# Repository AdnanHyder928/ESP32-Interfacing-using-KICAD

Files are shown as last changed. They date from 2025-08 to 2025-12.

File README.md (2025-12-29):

<h1>Schematic Section</h1>


<h1>PCB Section</h1>


<h1>3D Model of PCB</h1>

Some 3D models are missing, but the footprints are there.

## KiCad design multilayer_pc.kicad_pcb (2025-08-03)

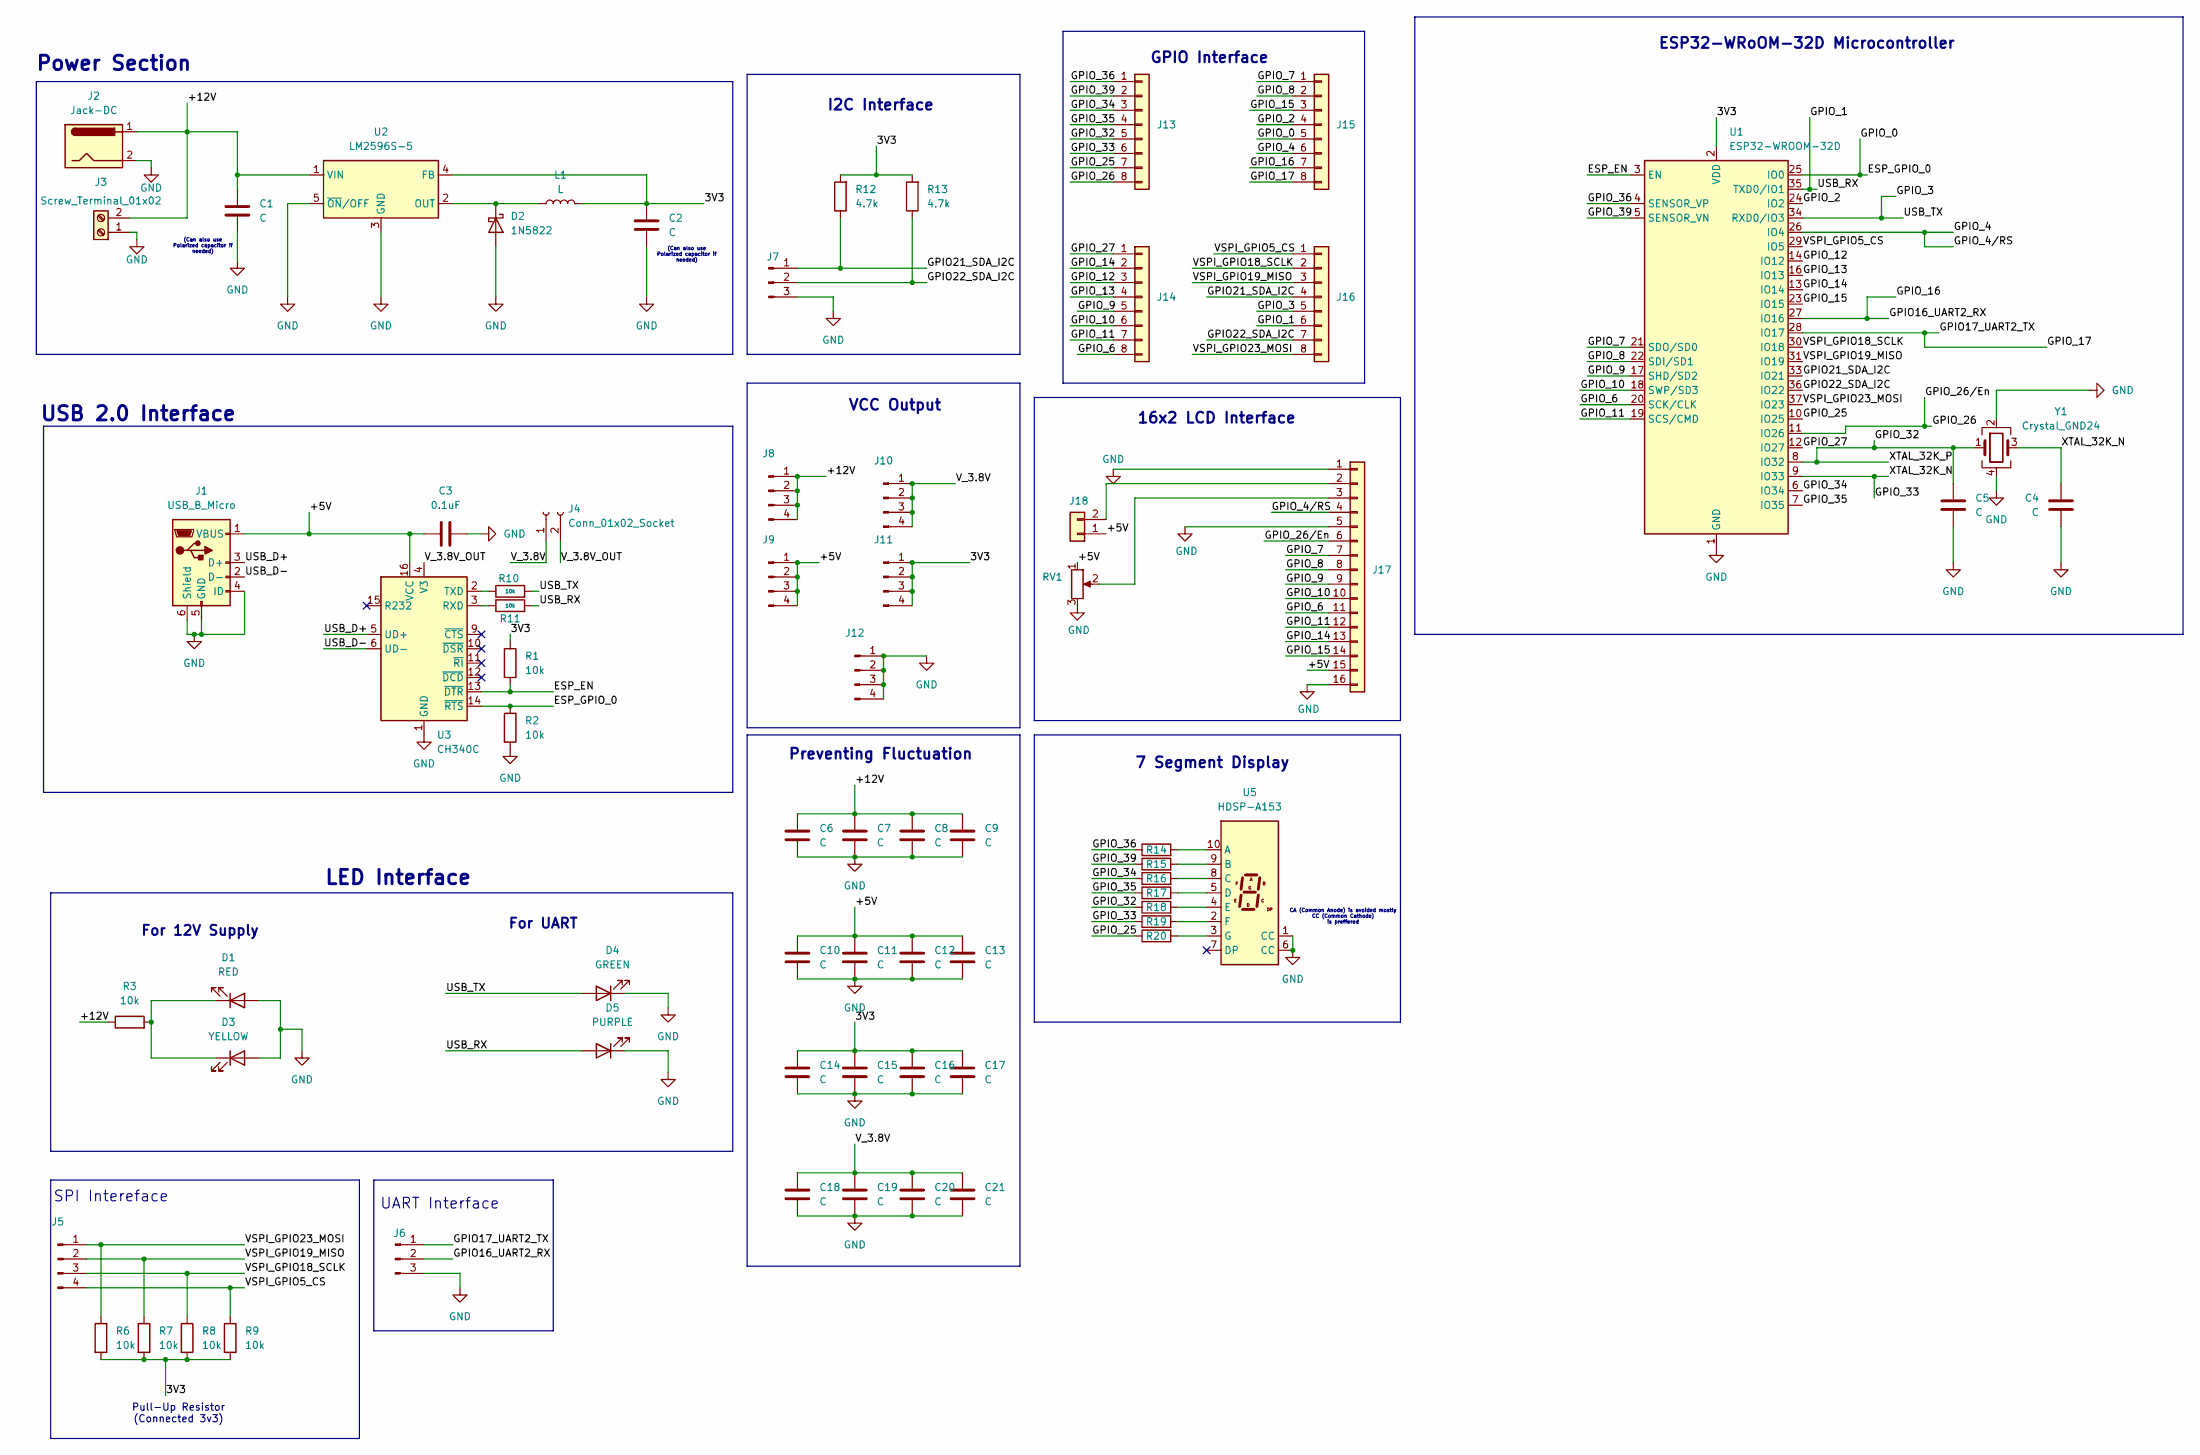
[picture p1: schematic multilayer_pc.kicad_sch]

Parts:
C1, C2, C4, C5, C6, C7, C8, C9, C10, C11, C12, C13, C14, C15, C16, C17, C18, C19, C20, C21: C; C_0805_2012Metric
C3: 0.1uF; C_0805_2012Metric
D1: RED; LED_0805_2012Metric
D2: 1N5822; D_DO-201AD_P15.24mm_Horizontal
D3: YELLOW; LED_0805_2012Metric
D4: GREEN; LED_0805_2012Metric
D5: PURPLE; LED_0805_2012Metric
J1: USB_B_Micro; USB_Micro-AB_Molex_47590-0001
J2: Jack-DC; BarrelJack_SwitchcraftConxall_RAPC10U_Horizontal
J3: Screw_Terminal_01x02; TerminalBlock_bornier-2_P5.08mm
J4: Conn_01x02_Socket; Molex_SL_171971-0002_1x02_P2.54mm_Vertical
J5, J8, J9, J10, J11, J12: Conn_01x04_Pin; FanPinHeader_1x04_P2.54mm_Vertical
J6, J7: Conn_01x03_Pin; FanPinHeader_1x03_P2.54mm_Vertical
J13, J14, J15, J16: Conn_01x08; Molex_KK-254_AE-6410-08A_1x08_P2.54mm_Vertical
J17: Conn_01x16; PinHeader_1x16_P2.54mm_Vertical
J18: Conn_01x02; PinHeader_1x02_P2.54mm_Vertical
L1: L; L_0805_2012Metric_Pad1.05x1.20mm_HandSolder
R1, R2, R3, R6, R7, R8, R9, R10, R11: 10k; R_0805_2012Metric
R12, R13: 4.7k; R_0805_2012Metric
R14, R15, R16, R17, R18, R19, R20: R_0805_2012Metric
RV1: R_Potentiometer; Potentiometer_Vishay_148-149_Single_Horizontal
U1: ESP32-WROOM-32D
U2: LM2596S-5; TO-263-5_TabPin3
U3: CH340C; SOIC-16_3.9x9.9mm_P1.27mm
U5: HDSP-A153; HDSP-A151
Y1: Crystal_GND24; Crystal_SMD_0603-2Pin_6.0x3.5mm

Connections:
/3V3: C2.1, C14.1, C15.1, C16.1, C17.1, J11.1, J11.2, J11.3, J11.4, L1.2, R1.1, R6.2, R7.2, R8.2, R9.2, R12.2, R13.2, U1.2 (VDD), U2.4 (FB)
/+5V: C3.1, C10.1, C11.1, C12.1, C13.1, J1.1 (VBUS), J9.1, J9.2, J9.3, J9.4, J17.15, J18.1, RV1.1, U3.16 (VCC)
/+12V: C1.1, C6.1, C7.1, C8.1, C9.1, J2.1, J3.2, J8.1, J8.2, J8.3, J8.4, R3.1, U2.1 (VIN)
/ESP_EN: R1.2, U1.3 (EN), U3.13 (~DTR)
/ESP_GPIO_0: J15.5, R2.1, U1.25 (IO0), U3.14 (~RTS)
/GPIO16_UART2_RX: J6.2, J15.7, U1.27 (IO16)
/GPIO17_UART2_TX: J6.1, J15.8, U1.28 (IO17)
/GPIO21_SDA_I2C: J7.1, J16.4, R12.1, U1.33 (IO21)
/GPIO22_SDA_I2C: J7.2, J16.7, R13.1, U1.36 (IO22)
/GPIO_1: D5.2 (A), J16.6, R11.2, U1.35 (TXD0/IO1); also elsewhere on the board
/GPIO_2: J15.4, U1.24 (IO2)
/GPIO_3: D4.2 (A), J16.5, R10.2, U1.34 (RXD0/IO3); also elsewhere on the board
/GPIO_4: J15.6, J17.4, U1.26 (IO4)
/GPIO_6: J14.8, J17.11, U1.20 (SCK/CLK)
/GPIO_7: J15.1, J17.7, U1.21 (SDO/SD0)
/GPIO_8: J15.2, J17.8, U1.22 (SDI/SD1)
/GPIO_9: J14.5, J17.9, U1.17 (SHD/SD2)
/GPIO_10: J14.6, J17.10, U1.18 (SWP/SD3)
/GPIO_11: J14.7, J17.12, U1.19 (SCS/CMD)
/GPIO_12: J14.3, U1.14 (IO12)
/GPIO_13: J14.4, U1.16 (IO13)
/GPIO_14: J14.2, J17.13, U1.13 (IO14)
/GPIO_15: J15.3, J17.14, U1.23 (IO15)
/GPIO_25: J13.7, R20.1, U1.10 (IO25)
/GPIO_26: J13.8, J17.6, U1.11 (IO26)
/GPIO_27: J14.1, U1.12 (IO27)
/GPIO_32: C5.1, J13.5, R18.1, U1.8 (IO32), Y1.1
/GPIO_33: C4.1, J13.6, R19.1, U1.9 (IO33), Y1.3
/GPIO_34: J13.3, R16.1, U1.6 (IO34)
/GPIO_35: J13.4, R17.1, U1.7 (IO35)
/GPIO_36: J13.1, R14.1, U1.4 (SENSOR_VP)
/GPIO_39: J13.2, R15.1, U1.5 (SENSOR_VN)
/USB_D+: J1.3 (D+), U3.5 (UD+)
/USB_D-: J1.2 (D-), U3.6 (UD-)
/VSPI_GPIO5_CS: J5.4, J16.1, R9.1, U1.29 (IO5)
/VSPI_GPIO18_SCLK: J5.3, J16.2, R8.1, U1.30 (IO18)
/VSPI_GPIO19_MISO: J5.2, J16.3, R7.1, U1.31 (IO19)
/VSPI_GPIO23_MOSI: J5.1, J16.8, R6.1, U1.37 (IO23)
/V_3.8V: C18.1, C19.1, C20.1, C21.1, J4.1, J10.1, J10.2, J10.3, J10.4
/V_3.8V_OUT: J4.2, U3.4 (V3)
GND: C1.2, C2.2, C3.2, C4.2, C5.2, C6.2, C7.2, C8.2, C9.2, C10.2, C11.2, C12.2, C13.2, C14.2, C15.2, C16.2, C17.2, C18.2, C19.2, C20.2, C21.2, D1.2 (A), D2.2 (A), D3.2 (A), D4.1 (K), D5.1 (K), J1.4 (ID), J1.5 (GND), J1.6 (Shield), J2.2, J3.1, J6.3, J7.3, J12.1, J12.2, J12.3, J12.4, J17.1, J17.5, J17.16, R2.2, RV1.3, U1.1 (GND), U1.15 (GND), U1.38 (GND), U1.39 (GND), U2.3 (GND), U2.5 (~ON/OFF), U3.1 (GND), U5.1 (CC), U5.6 (CC), Y1.2, Y1.4
unnamed: D1.1 (K), D3.1 (K), R3.2
unnamed: D2.1 (K), L1.1, U2.2 (OUT)
unnamed: J17.2, J18.2
unnamed: J17.3, RV1.2
unnamed: R11.1, U3.3 (RXD)
unnamed: R10.1, U3.2 (TXD)
unnamed: R14.2, U5.10 (A)
unnamed: R15.2, U5.9 (B)
unnamed: R16.2, U5.8 (C)
unnamed: R17.2, U5.5 (D)
unnamed: R18.2, U5.4 (E)
unnamed: R19.2, U5.2 (F)
unnamed: R20.2, U5.3 (G)

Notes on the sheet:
CA (Common Anode) is avoided mostly CC (Common Cathode) is preffered
GPIO Interface
VCC Output
For 12V Supply
For UART
(Can also use Polarized capacitor if needed)
I2C Interface
16x2 LCD Interface
SPI Intereface
7 Segment Display
Preventing Fluctuation
Pull-Up Resistor (Connected 3v3)
Power Section
USB 2.0 Interface
LED Interface
UART Interface
ESP32-WRoOM-32D Microcontroller

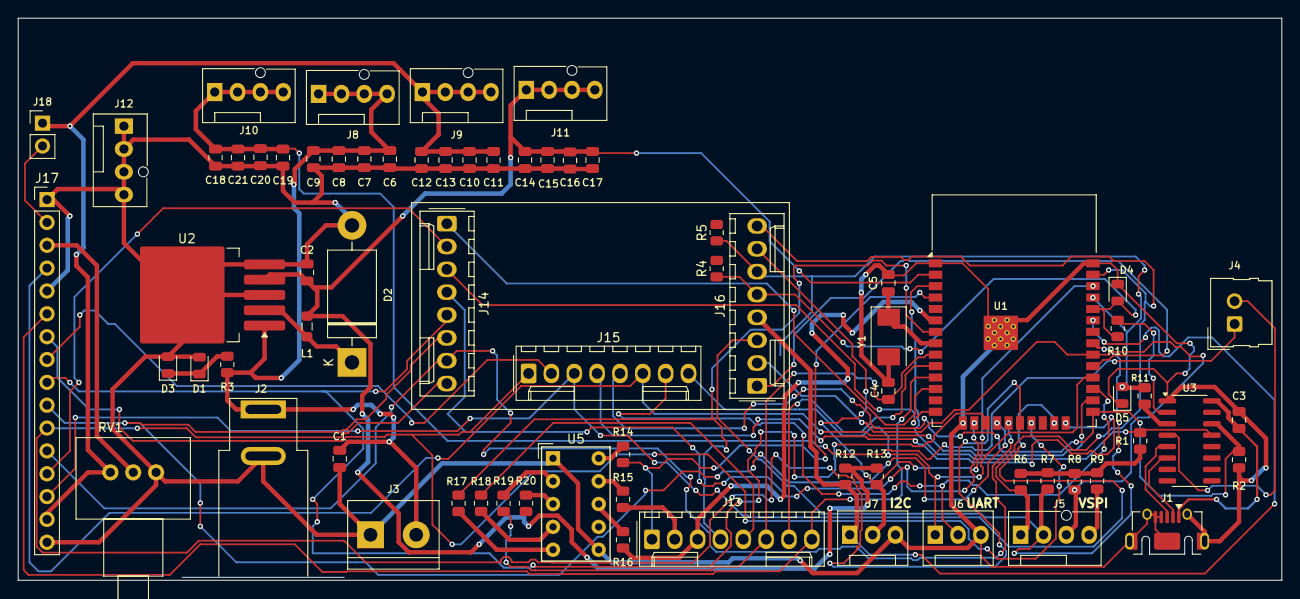
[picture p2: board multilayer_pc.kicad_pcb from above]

Board: 2 copper layers, 140.5 x 62.5 mm, 71 parts (0 on the bottom side), 54 nets.

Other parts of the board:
R4, R5: 10k; R_0805_2012Metric

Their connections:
/GPIO_1: R5.1; also elsewhere on the board
/GPIO_3: R4.1; also elsewhere on the board

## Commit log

2025-04-14 Initial Commit with schematic only (Part 1)
    [multilayer_pc.kicad_pcb, multilayer_pc.kicad_sch]
2025-08-03 Updated The PCB of the Project
    [multilayer_pc.kicad_pcb, multilayer_pc.kicad_sch]
2025-12-29 Add schematic, PCB, and 3D model sections to README
    Added schematic, PCB, and 3D model sections with images.
